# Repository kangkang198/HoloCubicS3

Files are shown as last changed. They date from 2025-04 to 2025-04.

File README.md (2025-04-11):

# HoloCubicS3(AI语音版)
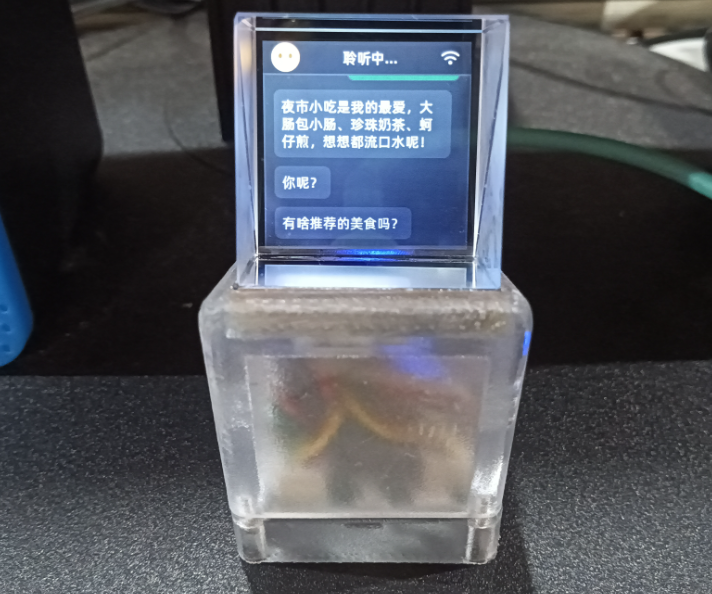
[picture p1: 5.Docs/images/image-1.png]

## 项目介绍
这是HoloCubic的AI语音版本。刚开始其实只是想让HoloCubic播放有声的音视频，在原版的基础上添加麦克风和扬声器的接口。但后面小智AI爆火后，希望可以制作一个可以跑小智AI的HoloCubic。
>由于用到ESP32S3主控芯片，所以项目名称改为HoloCubicS3，用于区分原版。

### 下面从硬件、固件、软件、结构4个方面进一步介绍。

## 1.硬件
硬件我主要讲一下与原版的差异点。
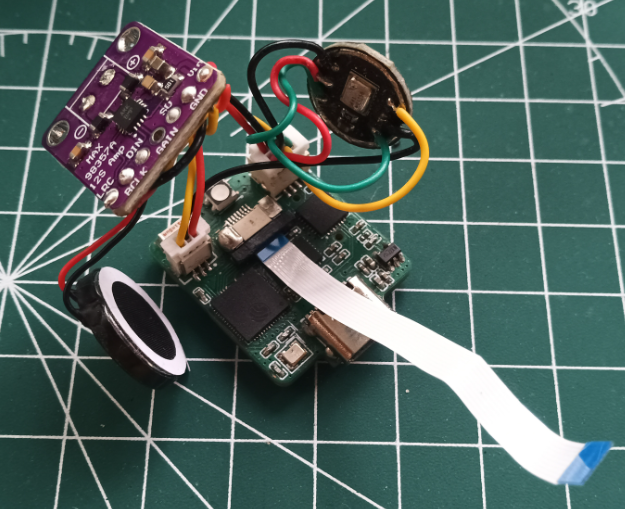
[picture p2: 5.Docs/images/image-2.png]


### 1.1 主控选型
主控从ESP32-PICO-D4换成了性能更好，内存更大的ESP32S3。型号是ESP32S3R8,一样是QFN封装的芯片，它内置了8MB PSRAM，所以内存肯定是够用了。
>当然，还需要外挂一块SPI FLASH用来存放代码，这里我选用了一块8MB的SPI FLASH，感觉应该够用了。如果有容量要求，也可以选用容量更大的16MB的SPI FLASH。

### 1.2 语音拓展
语音拓展我这里用了比较偷懒的办法,就是直接在主板上留出2个I2S接口，搭配网上购买的MAX98357音频功放板和INMP441全向麦克风模块来实现的,这两个模块好像在
创客圈里经常被拿来使用，所以这里就选了这两个模块。
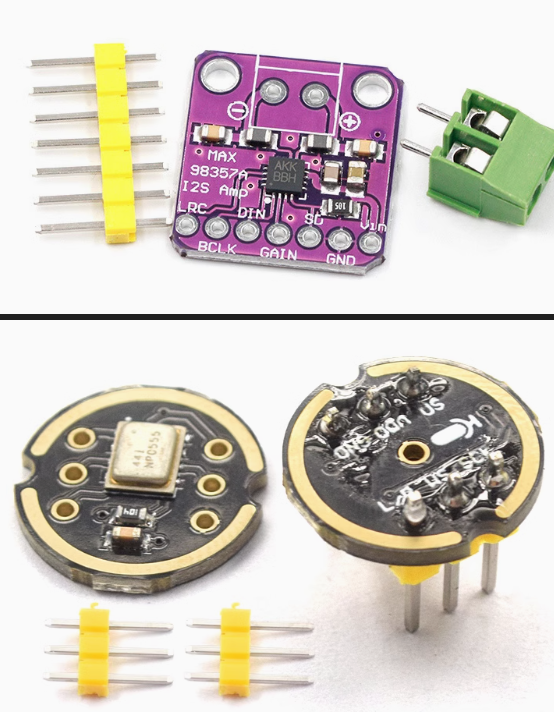
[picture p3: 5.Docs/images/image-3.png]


喇叭这里使用的是16MM-8Ω 1W-L60MM的小喇叭。

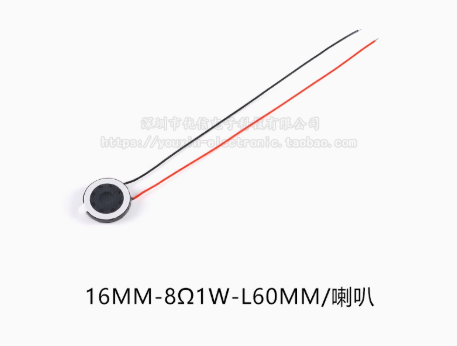
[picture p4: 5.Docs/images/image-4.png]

>注: INMP441上的L/R是左右声道选择端，我程序里面是用了左声道，需要把该L/R端接到GND。MAX98357的VDD选择接5V，这样可以减少播放音频中的噪声。

### 1.3 SD卡座修改
原版的SD卡座没有自弹功能,而且每次取出SD卡都要先拧出下壳的螺丝，打开下壳，拿出主板才能取出。我觉得这点比较麻烦，不够优雅。考虑到需要用来播放音视频，可能需要频繁取出SD卡来更换音频和视频素材，所以修改了SD卡座为带自弹功能的。

### 1.4 USB转串口芯片修改
原来的CP2102芯片比较贵，所以修改为更便宜的国产CH9102X芯片，两块芯片的封装是pin to pin的，方便随时替换。
>如果想省成本可以换成使用CH9102X，想性能稳定可以用回CP2102。

## 2.固件
固件方面目前适配了以下3个开源项目：
* **小智AI**：可以用来作为AI语音聊天机器人。
* **MiniTV**：可以用来播放音视频。
* **HoloCubic AIO**：这个固件其实还没完全适配好，会有重启的问题，这里我也开源了，如果有能力同学的也可以修复完善一下。

>其中开发小智AI的IDE我是使用VSCode + ESP-IDF插件来开发的，ESP-IDF版本是v5.3.2。
开发MiniTV和HoloCubic AIO的IDE是使用VSCode + Platformio插件来开发的，当然也可以换成Arduino IDE。

## 3.软件
如果需要播放音视频，就需要用到ffmpeg这个开源软件把原始的视频转换出音频和视频文件。
这个软件使用时把软件目录下的bin目录添加到系统环境变量可以更方便的使用。如我添加到环境变量的目录是:
```
D:\ffmpeg-2025-03-31-git-35c091f4b7-essentials_build\bin
```
然后就可以使用命令行提示符，进入需要转换的视频所在的目录，依次输入以下指令来转换视频和音频。为了方便，我把视频名称改成了input.mp4。

### AAC Audio

#### 44.1 kHz Mono

```
ffmpeg -i input.mp4 -ar 44100 -ac 1 -ab 24k -filter:a loudnorm -filter:a "volume=-5dB" 44100.aac
```

### MP3 Audio

#### 44.1 kHz Mono

```
ffmpeg -i input.mp4 -ar 44100 -ac 1 -ab 32k -filter:a loudnorm -filter:a "volume=-5dB" 44100.mp3
```
>上面的AAC音频和MP3音频是二选一，选择其中一种格式转换就行。
### MJPEG Video

#### 240x240@30fps

```
ffmpeg -i input.mp4 -vf "fps=30,scale=-1:240:flags=lanczos,crop=240:in_h:(in_w-240)/2:0" -q:v 11 240_30fps.mjpeg
```

## 4.结构
结构分为上壳和下壳，上壳我把里面的空间扩大了，方便塞下音频功放板和麦克风模块。下壳的侧面还留出了一个SD的卡槽，方便随时取下SD卡修改SD卡的内容。
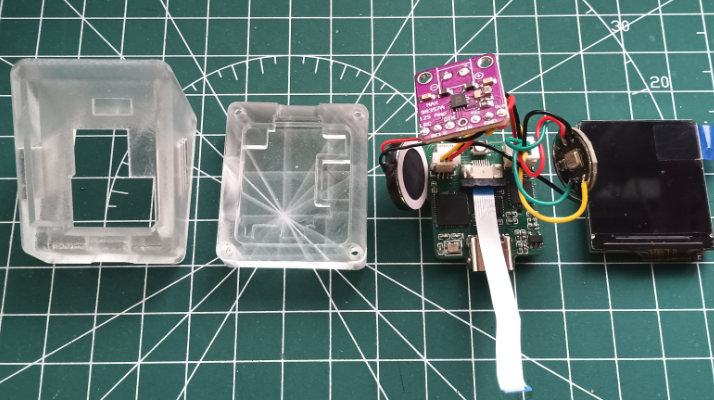
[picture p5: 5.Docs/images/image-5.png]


上下壳我是使用螺丝固定的，型号是M1.6*6
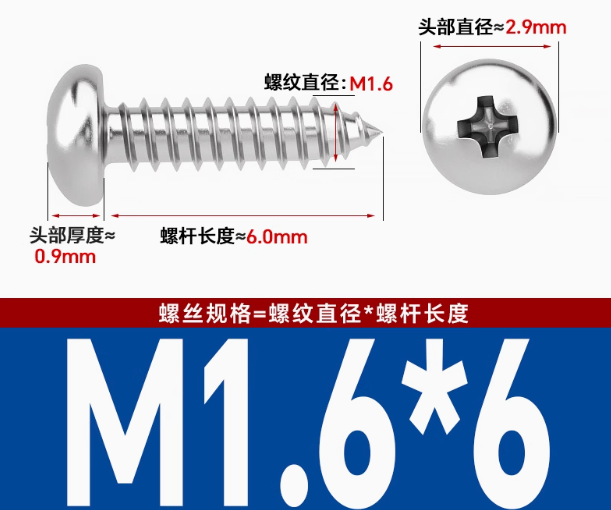
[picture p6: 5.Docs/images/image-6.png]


## 5.开源致谢
感谢以下开源项目:

https://github.com/peng-zhihui/HoloCubic

https://github.com/78/xiaozhi-esp32

https://github.com/moononournation/MiniTV

https://github.com/ClimbSnail/HoloCubic_AIO

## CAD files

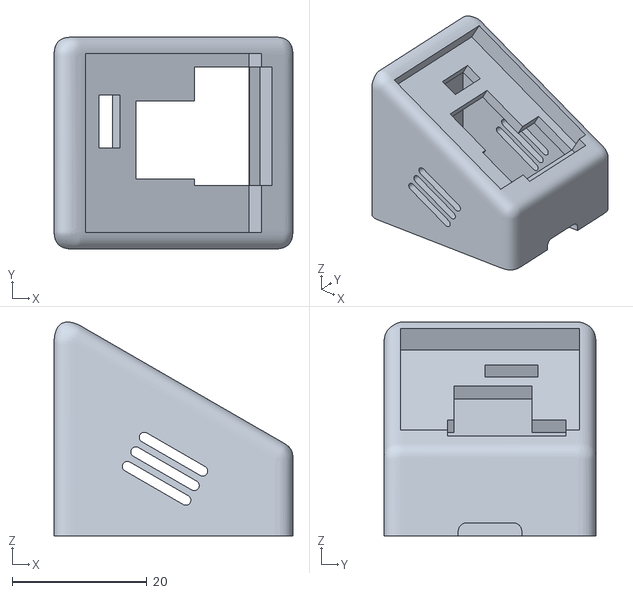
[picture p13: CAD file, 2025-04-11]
4.Model/Upper.STL
35.5 x 31.5 x 31.8

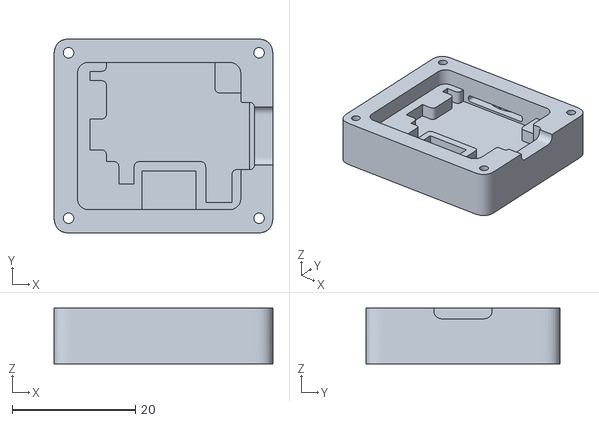
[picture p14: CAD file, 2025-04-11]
4.Model/Lower.STL
35.5 x 31.5 x 9.00

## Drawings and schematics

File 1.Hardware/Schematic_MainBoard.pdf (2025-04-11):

## U1GND 57

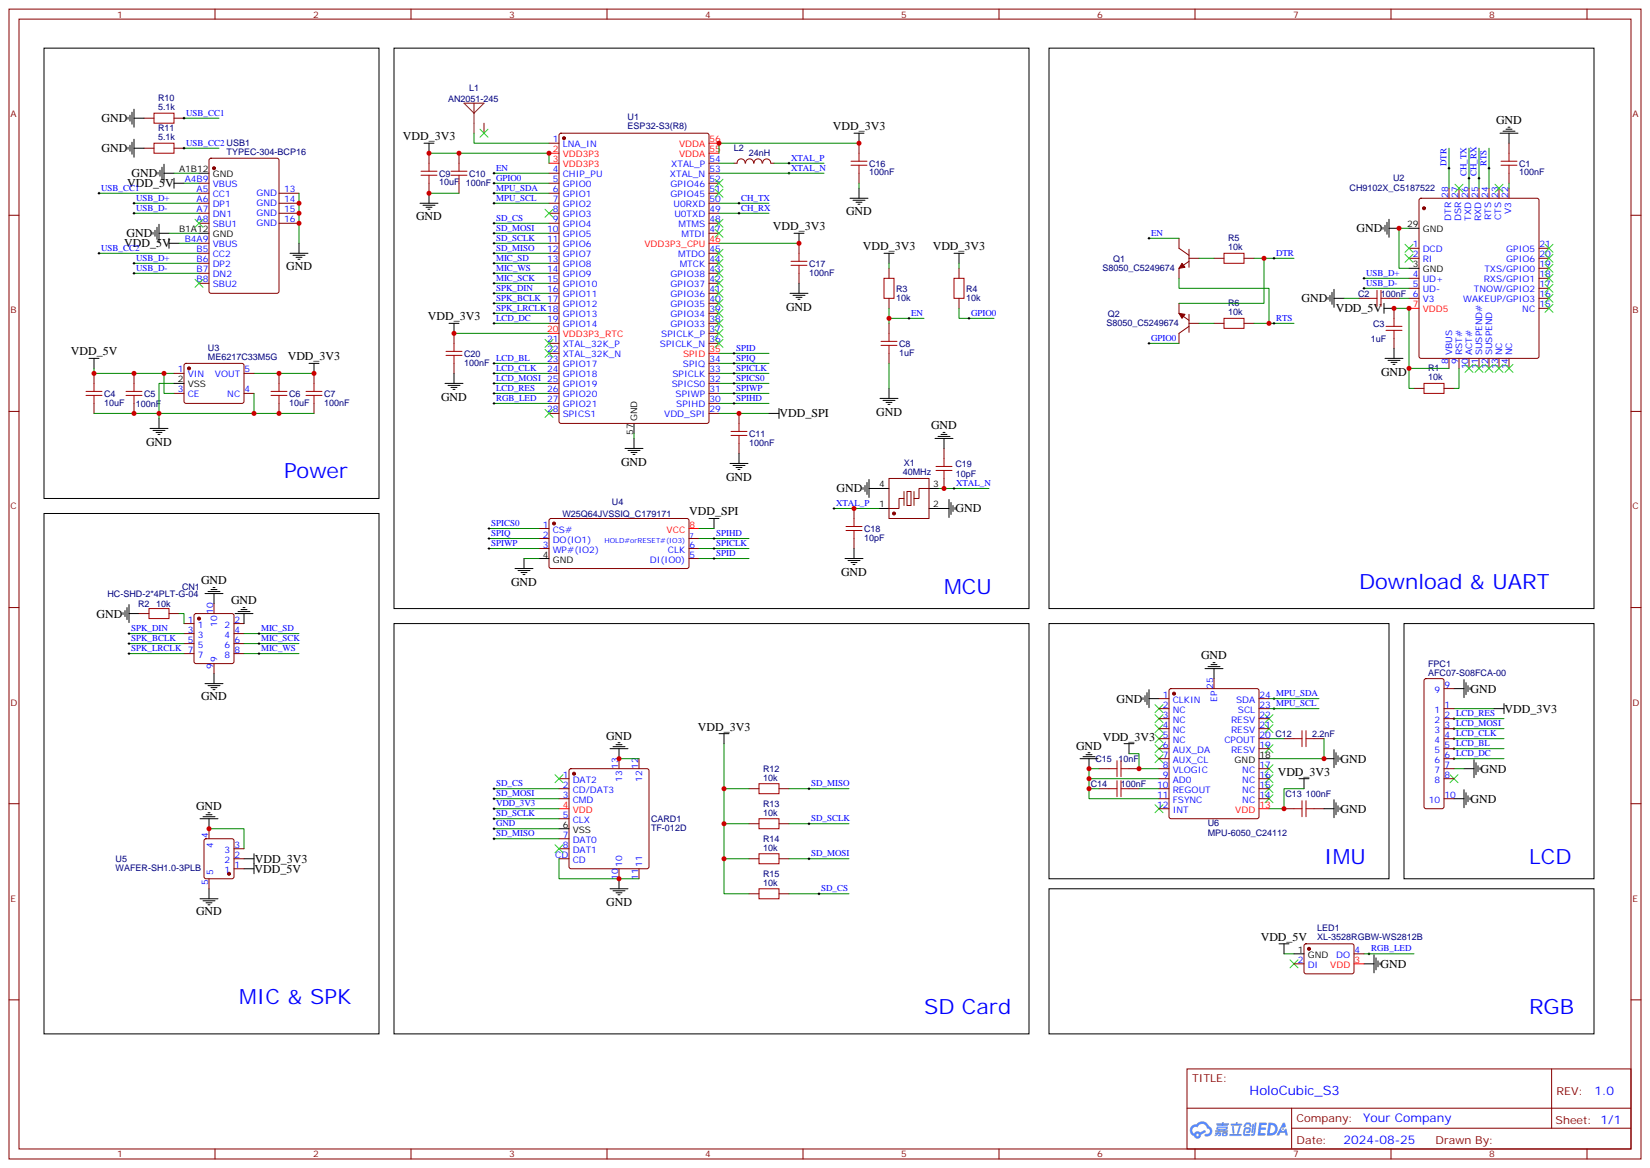
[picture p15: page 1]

GND 16 GND 15 GND 14 GND 13

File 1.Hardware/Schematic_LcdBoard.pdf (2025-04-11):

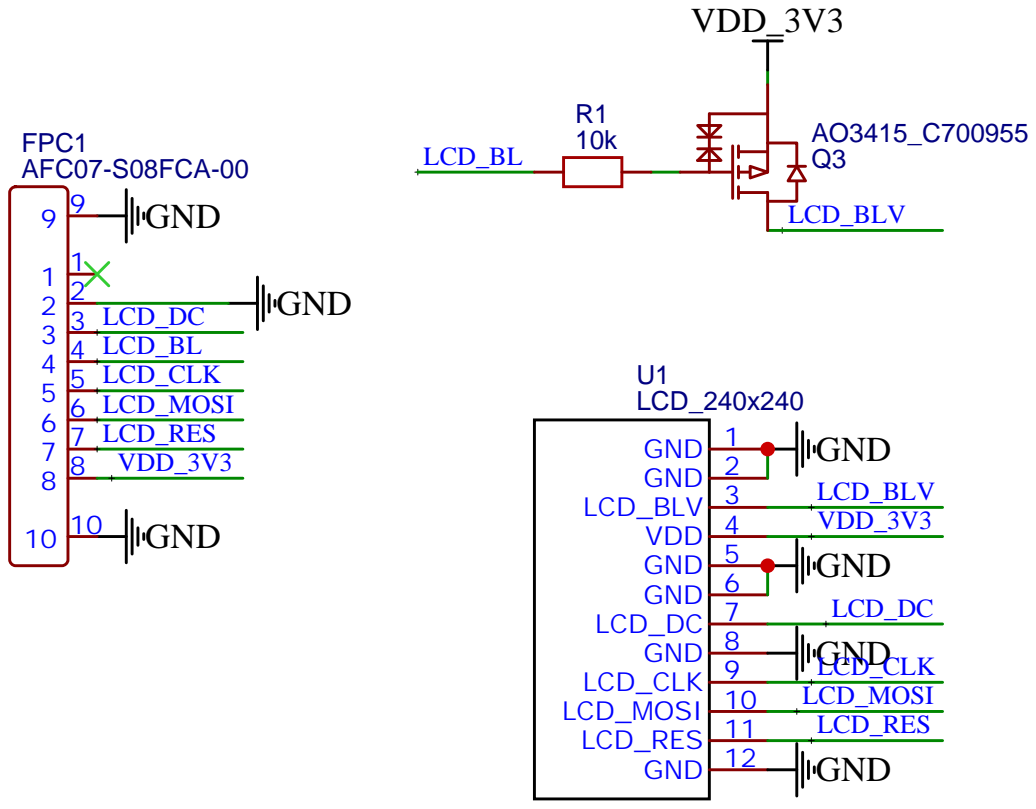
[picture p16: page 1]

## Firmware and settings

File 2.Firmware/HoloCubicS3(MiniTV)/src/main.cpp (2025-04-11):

/***
 * Required libraries:
 * Arduino_GFX: https://github.com/moononournation/Arduino_GFX.git
 * libhelix: https://github.com/pschatzmann/arduino-libhelix.git
 */
// auto fall back to MP3 if AAC file not available
#define AAC_FILENAME "/44100.aac"
#define MP3_FILENAME "/44100.mp3"
#define MJPEG_FILENAME "/240_30fps.mjpeg"
#define FPS 30
#define MJPEG_BUFFER_SIZE (240 * 240 * 2 / 4)
#define AUDIOASSIGNCORE 1

#include <WiFi.h>
#include <SD.h>
#include <SD_MMC.h>
#include <driver/i2s.h>

#include <Arduino_GFX_Library.h>
// #define TFT_BL -1
// #define TFT_BRIGHTNESS 128
Arduino_HWSPI *bus = new Arduino_HWSPI(14 /* DC */, -1 /* CS */, 18 /* SCK */, 19 /* MOSI */, -1 /* MISO */);
Arduino_GFX *gfx = new Arduino_ST7789(bus, 20 /* RST */, 4 /* rotation */, true /* IPS */, 240 /* width */, 240 /* height */, 0 /* col offset 1 */, 0 /* row offset 1 */);

/* audio */
#include "esp32_audio_task.h"

/* MJPEG Video */
#include "MjpegClass.h"
static MjpegClass mjpeg;

int next_frame = 0;
int skipped_frames = 0;
unsigned long total_read_video_ms = 0;
unsigned long total_play_video_ms = 0;
unsigned long total_remain = 0;
unsigned long start_ms, curr_ms, next_frame_ms;
void setup()
{
  WiFi.mode(WIFI_OFF);
  Serial.begin(115200);

  // Init Video
  gfx->begin();
  gfx->fillScreen(BLACK);

#ifdef TFT_BL
  ledcAttachPin(TFT_BL, 1);     // assign TFT_BL pin to channel 1
  ledcSetup(1, 12000, 8);       // 12 kHz PWM, 8-bit resolution
  ledcWrite(1, TFT_BRIGHTNESS); // brightness 0 - 255
#endif

  Serial.println("Init I2S");
  gfx->println("Init I2S");
  esp_err_t ret_val = i2s_init(I2S_NUM_0, 44100, -1 /* MCLK */, 12 /* SCLK */, 13 /* LRCK */, 11 /* DOUT */, -1 /* DIN */);

  if (ret_val != ESP_OK)
  {
    Serial.printf("i2s_init failed: %d\n", ret_val);
  }
  i2s_zero_dma_buffer(I2S_NUM_0);

  Serial.println("Init FS");
  gfx->println("Init FS");

  // Init SD card
  SPIClass spi = SPIClass(HSPI);
  spi.begin(6/* SCK */, 7 /* MISO */, 5 /* MOSI */, 4 /* SS */);
  if (!SD.begin(4 /* SS */, spi, 80000000))
  {
    Serial.println("ERROR: File system mount failed!");
    gfx->println("ERROR: File system mount failed!");
  }
  else
  {
    bool aac_file_available = false;
    Serial.println("Open AAC file: " AAC_FILENAME);
    gfx->println("Open AAC file: " AAC_FILENAME);
    // File aFile = LittleFS.open(AAC_FILENAME);
    // File aFile = SPIFFS.open(AAC_FILENAME);
    // File aFile = FFat.open(AAC_FILENAME);
    File aFile = SD.open(AAC_FILENAME);
    // File aFile = SD_MMC.open(AAC_FILENAME);
    if (aFile)
    {
      aac_file_available = true;
    }
    else
    {
      Serial.println("Open MP3 file: " MP3_FILENAME);
      gfx->println("Open MP3 file: " MP3_FILENAME);
      // aFile = LittleFS.open(MP3_FILENAME);
      // aFile = SPIFFS.open(MP3_FILENAME);
      // aFile = FFat.open(MP3_FILENAME);
      aFile = SD.open(MP3_FILENAME);
      // aFile = SD_MMC.open(MP3_FILENAME);
    }

    if (!aFile || aFile.isDirectory())
    {
      Serial.println("ERROR: Failed to open " AAC_FILENAME " or " MP3_FILENAME " file for reading");
      gfx->println("ERROR: Failed to open " AAC_FILENAME " or " MP3_FILENAME " file for reading");
    }
    else
    {
      File vFile = SD.open(MJPEG_FILENAME);
      // File vFile = SD_MMC.open(MJPEG_FILENAME);
      if (!vFile || vFile.isDirectory())
      {
        Serial.println(F("ERROR: Failed to open " MJPEG_FILENAME " file for reading"));
        gfx->println(F("ERROR: Failed to open " MJPEG_FILENAME " file for reading"));
      }
      else
      {
          uint8_t *mjpeg_buf = (uint8_t *)malloc(MJPEG_BUFFER_SIZE);
          if (!mjpeg_buf)
          {
            Serial.println("mjpeg_buf malloc failed!");
          }
          else
          {
            Serial.println("Init video");
            gfx->println("Init video");
            mjpeg.setup(vFile, mjpeg_buf, (Arduino_TFT *)gfx, true);
            Serial.println("Start play audio task");
            gfx->println("Start play audio task");
            BaseType_t ret_val;
            if (aac_file_available)
            {
              ret_val = aac_player_task_start(&aFile, AUDIOASSIGNCORE);
            }
            else
            {
              ret_val = mp3_player_task_start(&aFile, AUDIOASSIGNCORE);
            }
            if (ret_val != pdPASS)
            {
              Serial.printf("Audio player task start failed: %d\n", ret_val);
              gfx->printf("Audio player task start failed: %d\n", ret_val);
            }

            Serial.println("Start play video");
            gfx->println("Start play video");
            start_ms = millis();
            curr_ms = millis();
            next_frame_ms = start_ms + (++next_frame * 1000 / FPS);

            while (vFile.available() && aFile.available())
            {
              // Read video
              mjpeg.readMjpegBuf();
              total_read_video_ms += millis() - curr_ms;
              curr_ms = millis();

              if (millis() < next_frame_ms) // check show frame or skip frame
              {
                // Play video
                mjpeg.drawJpg();
                total_play_video_ms += millis() - curr_ms;

                int remain_ms = next_frame_ms - millis();
                total_remain += remain_ms;
                if (remain_ms > 0)
                {
                  delay(remain_ms);
                }
              }
              else
              {
                ++skipped_frames;
                Serial.println("Skip frame");
              }

              curr_ms = millis();
              next_frame_ms = start_ms + (++next_frame * 1000 / FPS);
            }
            int time_used = millis() - start_ms;
            Serial.println("AV end");
            vFile.close();
            aFile.close();
            int played_frames = next_frame - 1 - skipped_frames;
            float fps = 1000.0 * played_frames / time_used;
            Serial.printf("Played frames: %d\n", played_frames);
            Serial.printf("Skipped frames: %d (%0.1f %%)\n", skipped_frames, 100.0 * skipped_frames / played_frames);
            Serial.printf("Time used: %d ms\n", time_used);
            Serial.printf("Expected FPS: %d\n", FPS);
            Serial.printf("Actual FPS: %0.1f\n", fps);
            Serial.printf("Read audio: %lu ms (%0.1f %%)\n", total_read_audio_ms, 100.0 * total_read_audio_ms / time_used);
            Serial.printf("Decode audio: %lu ms (%0.1f %%)\n", total_decode_audio_ms, 100.0 * total_decode_audio_ms / time_used);
            Serial.printf("Play audio: %lu ms (%0.1f %%)\n", total_play_audio_ms, 100.0 * total_play_audio_ms / time_used);
            Serial.printf("SD read MJPEG: %d ms (%0.1f %%)\n", total_read_video_ms, 100.0 * total_read_video_ms / time_used);
            Serial.printf("Play video: %d ms (%0.1f %%)\n", total_play_video_ms, 100.0 * total_play_video_ms / time_used);
            Serial.printf("Remain: %d ms (%0.1f %%)\n", total_remain, 100.0 * total_remain / time_used);

#define CHART_MARGIN 24
#define LEGEND_A_COLOR 0xE0C3
#define LEGEND_B_COLOR 0x33F7
#define LEGEND_C_COLOR 0x4D69
#define LEGEND_D_COLOR 0x9A74
#define LEGEND_E_COLOR 0xFBE0
#define LEGEND_F_COLOR 0xFFE6
#define LEGEND_G_COLOR 0xA2A5
            gfx->setCursor(0, 0);
            gfx->setTextColor(WHITE);
            gfx->printf("Played frames: %d\n", played_frames);
            gfx->printf("Skipped frames: %d (%0.1f %%)\n", skipped_frames, 100.0 * skipped_frames / played_frames);
            gfx->printf("Actual FPS: %0.1f\n\n", fps);
            int16_t r1 = ((gfx->height() - CHART_MARGIN - CHART_MARGIN) / 2);
            int16_t r2 = r1 / 2;
            int16_t cx = gfx->width() - gfx->height() + CHART_MARGIN + CHART_MARGIN - 1 + r1;
            int16_t cy = r1 + CHART_MARGIN;
            float arc_start = 0;
            float arc_end = max(2.0, 360.0 * total_read_audio_ms / time_used);
            for (int i = arc_start + 1; i < arc_end; i += 2)
            {
              gfx->fillArc(cx, cy, r1, r2, arc_start - 90.0, i - 90.0, LEGEND_D_COLOR);
            }
            gfx->fillArc(cx, cy, r1, r2, arc_start - 90.0, arc_end - 90.0, LEGEND_D_COLOR);
            gfx->setTextColor(LEGEND_D_COLOR);
            gfx->printf("Read audio:\n%0.1f %%\n", 100.0 * total_read_audio_ms / time_used);

            arc_start = arc_end;
            arc_end += max(2.0, 360.0 * total_play_audio_ms / time_used);
            for (int i = arc_start + 1; i < arc_end; i += 2)
            {
              gfx->fillArc(cx, cy, r1, r2, arc_start - 90.0, i - 90.0, LEGEND_C_COLOR);
            }
            gfx->fillArc(cx, cy, r1, r2, arc_start - 90.0, arc_end - 90.0, LEGEND_C_COLOR);
            gfx->setTextColor(LEGEND_C_COLOR);
            gfx->printf("Play audio:\n%0.1f %%\n", 100.0 * total_play_audio_ms / time_used);

            arc_start = arc_end;
            arc_end += max(2.0, 360.0 * total_read_video_ms / time_used);
            for (int i = arc_start + 1; i < arc_end; i += 2)
            {
              gfx->fillArc(cx, cy, r1, r2, arc_start - 90.0, i - 90.0, LEGEND_B_COLOR);
            }
            gfx->fillArc(cx, cy, r1, r2, arc_start - 90.0, arc_end - 90.0, LEGEND_B_COLOR);
            gfx->setTextColor(LEGEND_B_COLOR);
            gfx->printf("Read MJPEG:\n%0.1f %%\n", 100.0 * total_read_video_ms / time_used);

            arc_start = arc_end;
            arc_end += max(2.0, 360.0 * total_play_video_ms / time_used);
            for (int i = arc_start + 1; i < arc_end; i += 2)
            {
              gfx->fillArc(cx, cy, r1, 0, arc_start - 90.0, i - 90.0, LEGEND_A_COLOR);
            }
            gfx->fillArc(cx, cy, r1, 0, arc_start - 90.0, arc_end - 90.0, LEGEND_A_COLOR);
            gfx->setTextColor(LEGEND_A_COLOR);
            gfx->printf("Play video:\n%0.1f %%\n", 100.0 * total_play_video_ms / time_used);
        }
      }
    }
  }
#ifdef TFT_BL
  delay(60000);
  ledcDetachPin(TFT_BL);
#endif
}

void loop()
{
}

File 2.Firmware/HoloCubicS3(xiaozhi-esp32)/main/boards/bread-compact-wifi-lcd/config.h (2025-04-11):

#ifndef _BOARD_CONFIG_H_
#define _BOARD_CONFIG_H_

#include <driver/gpio.h>

#define AUDIO_INPUT_SAMPLE_RATE  16000
#define AUDIO_OUTPUT_SAMPLE_RATE 24000

// 如果使用 Duplex I2S 模式，请注释下面一行
#define AUDIO_I2S_METHOD_SIMPLEX

#ifdef AUDIO_I2S_METHOD_SIMPLEX

// #define AUDIO_I2S_MIC_GPIO_WS   GPIO_NUM_4
// #define AUDIO_I2S_MIC_GPIO_SCK  GPIO_NUM_5
// #define AUDIO_I2S_MIC_GPIO_DIN  GPIO_NUM_6
// #define AUDIO_I2S_SPK_GPIO_DOUT GPIO_NUM_7
// #define AUDIO_I2S_SPK_GPIO_BCLK GPIO_NUM_15
// #define AUDIO_I2S_SPK_GPIO_LRCK GPIO_NUM_16

#define AUDIO_I2S_MIC_GPIO_WS   GPIO_NUM_9
#define AUDIO_I2S_MIC_GPIO_SCK  GPIO_NUM_10
#define AUDIO_I2S_MIC_GPIO_DIN  GPIO_NUM_8
#define AUDIO_I2S_SPK_GPIO_DOUT GPIO_NUM_11
#define AUDIO_I2S_SPK_GPIO_BCLK GPIO_NUM_12
#define AUDIO_I2S_SPK_GPIO_LRCK GPIO_NUM_13

#else

#define AUDIO_I2S_GPIO_WS GPIO_NUM_4
#define AUDIO_I2S_GPIO_BCLK GPIO_NUM_5
#define AUDIO_I2S_GPIO_DIN  GPIO_NUM_6
#define AUDIO_I2S_GPIO_DOUT GPIO_NUM_7

#endif

#define BUILTIN_LED_GPIO        GPIO_NUM_21
// #define BUILTIN_LED_GPIO        GPIO_NUM_48
#define BOOT_BUTTON_GPIO        GPIO_NUM_0
#define TOUCH_BUTTON_GPIO       GPIO_NUM_NC
#define VOLUME_UP_BUTTON_GPIO   GPIO_NUM_NC
#define VOLUME_DOWN_BUTTON_GPIO GPIO_NUM_NC


// #define DISPLAY_BACKLIGHT_PIN GPIO_NUM_42
// #define DISPLAY_MOSI_PIN      GPIO_NUM_47
// #define DISPLAY_CLK_PIN       GPIO_NUM_21
// #define DISPLAY_DC_PIN        GPIO_NUM_40
// #define DISPLAY_RST_PIN       GPIO_NUM_45
// #define DISPLAY_CS_PIN        GPIO_NUM_41

#define DISPLAY_BACKLIGHT_PIN GPIO_NUM_NC
#define DISPLAY_MOSI_PIN      GPIO_NUM_19
#define DISPLAY_CLK_PIN       GPIO_NUM_18
#define DISPLAY_DC_PIN        GPIO_NUM_14
#define DISPLAY_RST_PIN       GPIO_NUM_20
#define DISPLAY_CS_PIN        GPIO_NUM_NC


#ifdef CONFIG_LCD_ST7789_240X320
#define LCD_TYPE_ST7789_SERIAL
#define DISPLAY_WIDTH   240
#define DISPLAY_HEIGHT  320
#define DISPLAY_MIRROR_X false
#define DISPLAY_MIRROR_Y false
#define DISPLAY_SWAP_XY false
#define DISPLAY_INVERT_COLOR    true
#define DISPLAY_RGB_ORDER  LCD_RGB_ELEMENT_ORDER_RGB
#define DISPLAY_OFFSET_X  0
#define DISPLAY_OFFSET_Y  0
#define DISPLAY_BACKLIGHT_OUTPUT_INVERT false
#define DISPLAY_SPI_MODE 0
#endif

#ifdef CONFIG_LCD_ST7789_240X320_NO_IPS
#define LCD_TYPE_ST7789_SERIAL
#define DISPLAY_WIDTH   240
#define DISPLAY_HEIGHT  320
#define DISPLAY_MIRROR_X false
#define DISPLAY_MIRROR_Y false
#define DISPLAY_SWAP_XY false
#define DISPLAY_INVERT_COLOR    false
#define DISPLAY_RGB_ORDER  LCD_RGB_ELEMENT_ORDER_RGB
#define DISPLAY_OFFSET_X  0
#define DISPLAY_OFFSET_Y  0
#define DISPLAY_BACKLIGHT_OUTPUT_INVERT false
#define DISPLAY_SPI_MODE 0
#endif

#ifdef CONFIG_LCD_ST7789_170X320
#define LCD_TYPE_ST7789_SERIAL
#define DISPLAY_WIDTH   170
#define DISPLAY_HEIGHT  320
#define DISPLAY_MIRROR_X false
#define DISPLAY_MIRROR_Y false
#define DISPLAY_SWAP_XY false
#define DISPLAY_INVERT_COLOR    true
#define DISPLAY_RGB_ORDER  LCD_RGB_ELEMENT_ORDER_RGB
#define DISPLAY_OFFSET_X  35
#define DISPLAY_OFFSET_Y  0
#define DISPLAY_BACKLIGHT_OUTPUT_INVERT false
#define DISPLAY_SPI_MODE 0
#endif

#ifdef CONFIG_LCD_ST7789_172X320
#define LCD_TYPE_ST7789_SERIAL
#define DISPLAY_WIDTH   172
#define DISPLAY_HEIGHT  320
#define DISPLAY_MIRROR_X false
#define DISPLAY_MIRROR_Y false
#define DISPLAY_SWAP_XY false
#define DISPLAY_INVERT_COLOR    true
#define DISPLAY_RGB_ORDER  LCD_RGB_ELEMENT_ORDER_RGB
#define DISPLAY_OFFSET_X  34
#define DISPLAY_OFFSET_Y  0
#define DISPLAY_BACKLIGHT_OUTPUT_INVERT false
#define DISPLAY_SPI_MODE 0
#endif

#ifdef CONFIG_LCD_ST7789_240X280
#define LCD_TYPE_ST7789_SERIAL
#define DISPLAY_WIDTH   240
#define DISPLAY_HEIGHT  280
#define DISPLAY_MIRROR_X false
#define DISPLAY_MIRROR_Y false
#define DISPLAY_SWAP_XY false
#define DISPLAY_INVERT_COLOR    true
#define DISPLAY_RGB_ORDER  LCD_RGB_ELEMENT_ORDER_RGB
#define DISPLAY_OFFSET_X  0
#define DISPLAY_OFFSET_Y  20
#define DISPLAY_BACKLIGHT_OUTPUT_INVERT false
#define DISPLAY_SPI_MODE 0
#endif

#ifdef CONFIG_LCD_ST7789_240X240
#define LCD_TYPE_ST7789_SERIAL
#define DISPLAY_WIDTH   240
#define DISPLAY_HEIGHT  240
#define DISPLAY_MIRROR_X true
#define DISPLAY_MIRROR_Y false
#define DISPLAY_SWAP_XY false
#define DISPLAY_INVERT_COLOR    true
#define DISPLAY_RGB_ORDER  LCD_RGB_ELEMENT_ORDER_RGB
#define DISPLAY_OFFSET_X  0
#define DISPLAY_OFFSET_Y  0
#define DISPLAY_BACKLIGHT_OUTPUT_INVERT false
#define DISPLAY_SPI_MODE 3
#endif

#ifdef CONFIG_LCD_ST7789_240X240_7PIN
#define LCD_TYPE_ST7789_SERIAL
#define DISPLAY_WIDTH   240
#define DISPLAY_HEIGHT  240
#define DISPLAY_MIRROR_X false
#define DISPLAY_MIRROR_Y false
#define DISPLAY_SWAP_XY false
#define DISPLAY_INVERT_COLOR    true
#define DISPLAY_RGB_ORDER  LCD_RGB_ELEMENT_ORDER_RGB
#define DISPLAY_OFFSET_X  0
#define DISPLAY_OFFSET_Y  0
#define DISPLAY_BACKLIGHT_OUTPUT_INVERT false
#define DISPLAY_SPI_MODE 3
#endif
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

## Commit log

2025-04-11 first commit
    commit Hardware ,Model, Docs files
    [Lower.STL, Upper.STL]
2025-04-11 commit Firmware files
    commit HoloCubicS3(AIO)
    [partitions-no-ota.csv]
2025-04-11 commit Firmware files
    commit HoloCubicS3(xiaozhi-esp32)
    [partitions.csv, partitions_32M_sensecap.csv, partitions_4M.csv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]
